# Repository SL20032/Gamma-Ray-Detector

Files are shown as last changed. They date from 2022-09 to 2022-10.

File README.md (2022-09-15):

# Gamma Ray Detector
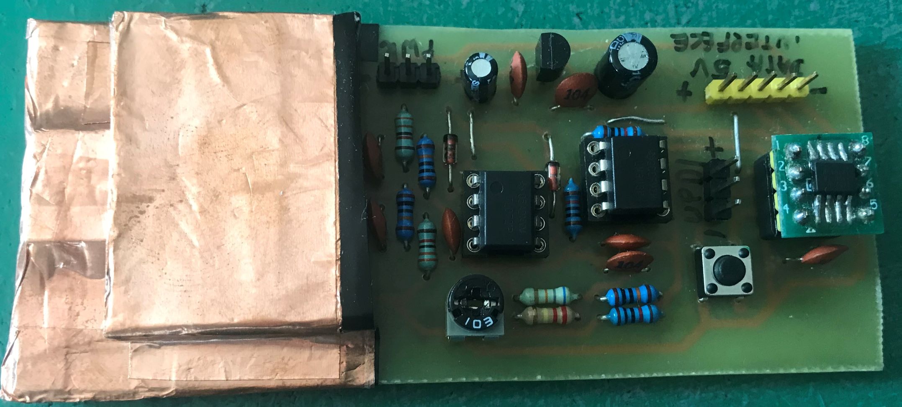
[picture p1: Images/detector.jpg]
Two head gamma particle detector

## Basic informations
Solid State gamma Ray detector based around PiN Diodeds (BPW34) as detection element and discreate transistor (BC549) as signal preamplifire (based on design published in Elektor magazine 06 - 2011). To increse detection rate of radiation while keeping good sensytivity espesialy for lower energy particles, device uses spit head approch - detection diodes are wired intu multiple detection heads (preamplifires) from witch output signal is then integrated and digitalized using compartor(LM393).

## Specs:
- Input voltage: 9V
- Data Procesing MCU: Attiny402 or pin compatible (so8 to dip8 adapter is nesesery in current board revision) 
## Theory of operation
TBA
## Digital signal procesing
Digital procesing is based on Attine402. Depending on the selected configuration data could be accese by a user e.g. through a COM port connection or an attached alfanumeric display. this solution supports counting all radioation events since device power up or counter reset (push button on the board) as well as a estimeted CPM (counts per minute). MCU firmware coming soon.
## Comparator circut calibration
To asure proper operation of detector's digital side nessesery is proper seting of reference voltage for comparator the easiest way to do this is:
- connect osciloscope to non inverting input of comparator (pin 3 on IC3) and to output of the same comparator (pin 1 on IC3)
- put the detector in area with minimal radiation (in most cases it is enought not to be in close procimty to ane designated sorce)
- dial the potenciometer (R19) until optput of a Comparator (IC3) stays low - set refernece voltage above a noice floor of a system
## Detection resoults 
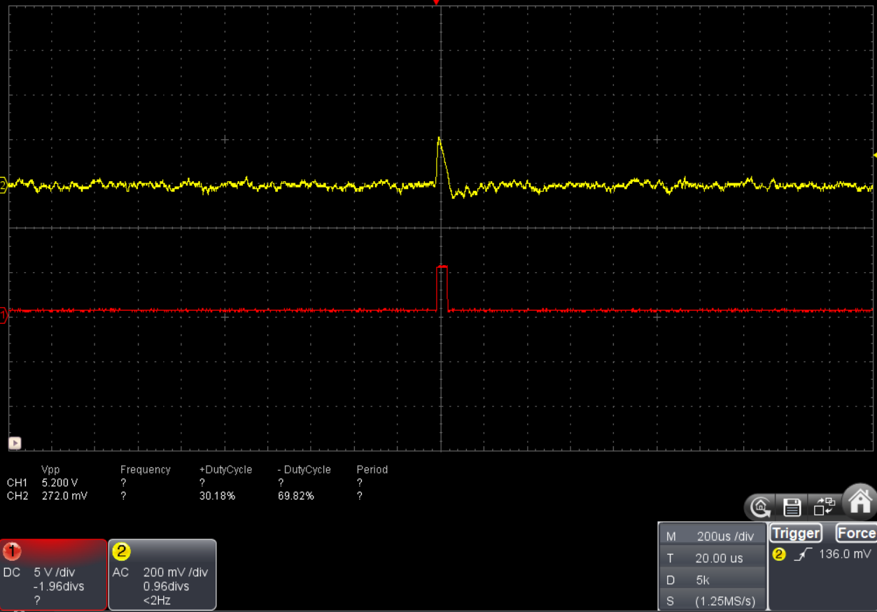
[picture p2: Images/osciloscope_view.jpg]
osciloscope view


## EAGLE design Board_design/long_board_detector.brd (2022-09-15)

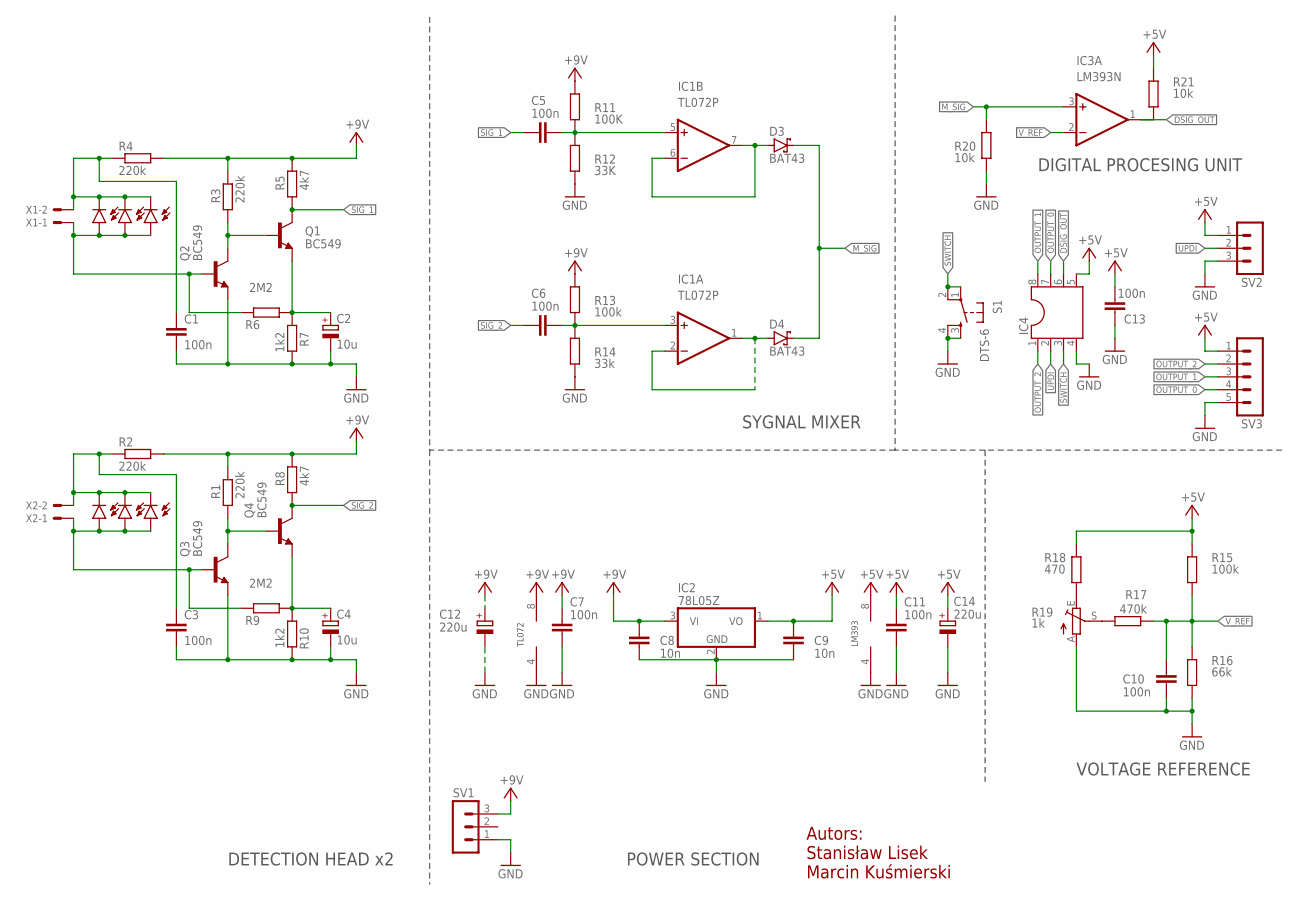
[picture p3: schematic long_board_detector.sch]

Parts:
C1, C3, C5, C6, C7, C10, C11, C13: 100n; C050-025X075
C2, C4: 10u; E2,5-6E
C8, C9: 10n; C050-025X075
C12, C14: 220u; E2,5-6E
D1, D2, D5, D6, D7, D8: BPW32
D3, D4: BAT43; DO35-10
IC1: TL072P; DIL08
IC2: 78L05Z; TO92
IC3: LM393N; DIL08
IC4: DIL8S; SOCKET-08
Q1, Q2, Q3, Q4: BC549; TO92-EBC
R1, R2, R3, R4: 220k; 0204/7
R5, R8: 4k7; 0204/7
R6, R9: 2M2; 0204/7
R7, R10: 1k2; 0204/7
R11: 100K; 0204/7
R12: 33K; 0204/7
R13, R15: 100k; 0204/7
R14: 33k; 0204/7
R16: 66k; 0204/7
R17: 470k; 0204/7
R18: 470; 0204/7
R19: 1k; CA6V
R20, R21: 10k; 0204/7
S1: DTS-6
SV1, SV2: MA03-1
SV3: MA05-1
X1, X2: 22-23-2021

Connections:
+3V3: C9.1, C11.2, C13.2, C14.+, IC2.1 (VO), IC3.8 (V+), IC4.5, R15.1, R18.2, R21.1, SV2.1, SV3.1
+5V: C7.2, C8.1, C12.+, IC1.8 (V+), IC2.3 (VI), R1.2, R2.2, R3.2, R4.2, R5.2, R8.2, R11.1, R13.1, SV1.3
DSIG_OUT: IC3.1 (OUT), IC4.6, R21.2
GND: C1.2, C2.-, C3.2, C4.-, C7.1, C8.2, C9.2, C10.2, C11.1, C12.-, C13.1, C14.-, IC1.4 (V-), IC2.2 (GND), IC3.4 (V-), IC4.4, Q2.E, Q3.E, R7.2, R10.2, R12.2, R14.2, R16.2, R19.A, R20.2, S1.3, S1.4, SV1.1, SV2.3, SV3.5
M_SIG: D3.C, D4.C, IC3.3 (+IN), R20.1
unnamed: D6.A, D7.A, D8.A, Q3.B, R9.2, X2.1
unnamed: C5.2, IC1.5 (+IN), R11.2, R12.1
unnamed: Q1.B, Q2.C, R3.1
unnamed: D1.A, D2.A, D5.A, Q2.B, R6.2, X1.1
unnamed: D4.A, IC1.1 (OUT), IC1.2 (-IN)
unnamed: D3.A, IC1.6 (-IN), IC1.7 (OUT)
unnamed: C2.+, Q1.E, R6.1, R7.1
unnamed: C6.2, IC1.3 (+IN), R13.2, R14.1
unnamed: C1.1, D1.K (C), D2.K (C), D5.K (C), R4.1, X1.2
unnamed: C3.1, D6.K (C), D7.K (C), D8.K (C), R2.1, X2.2
unnamed: Q3.C, Q4.B, R1.1
unnamed: C4.+, Q4.E, R9.1, R10.1
unnamed: R17.1, R19.S
unnamed: R18.1, R19.E
OUTPUT_0: IC4.7, SV3.4
OUTPUT_1: IC4.8, SV3.3
OUTPUT_2: IC4.1, SV3.2
SIG_1: C5.1, Q1.C, R5.1
SIG_2: C6.1, Q4.C, R8.1
SWITCH: IC4.3, S1.1, S1.2
UPDI: IC4.2, SV2.2
V_REF: C10.1, IC3.2 (-IN), R15.2, R16.1, R17.2

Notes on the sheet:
TL072
DETECTION HEAD x2
POWER SECTION
VOLTAGE REFERENCE
SYGNAL MIXER
DIGITAL PROCESING UNIT
LM393
Autors: Stanisław Lisek Marcin Kuśmierski

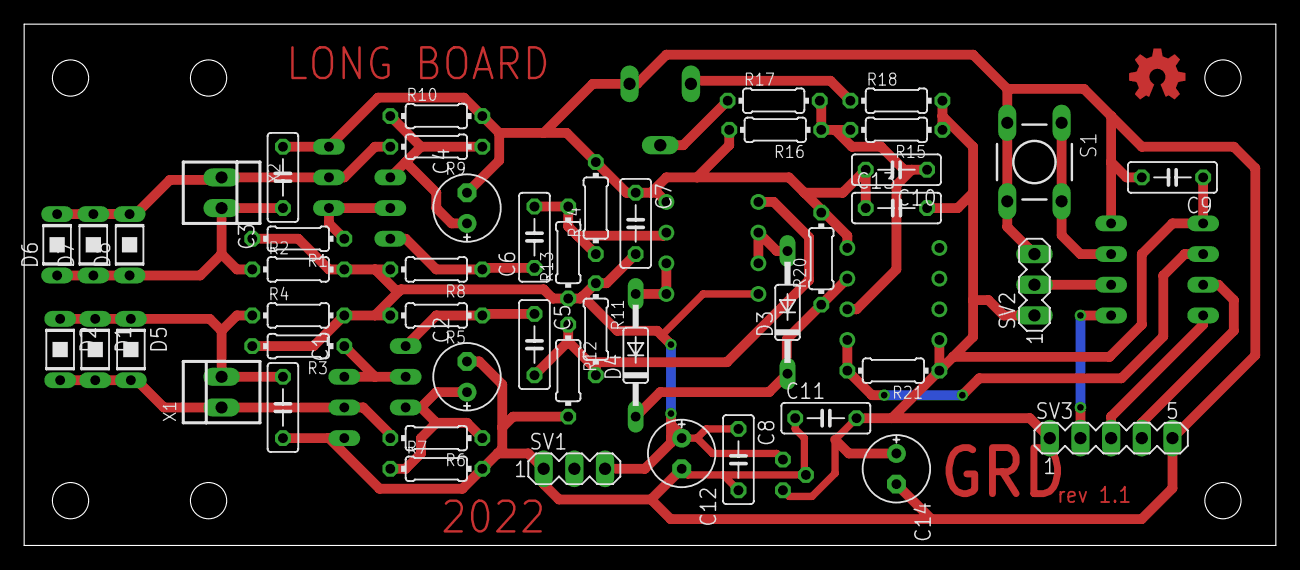
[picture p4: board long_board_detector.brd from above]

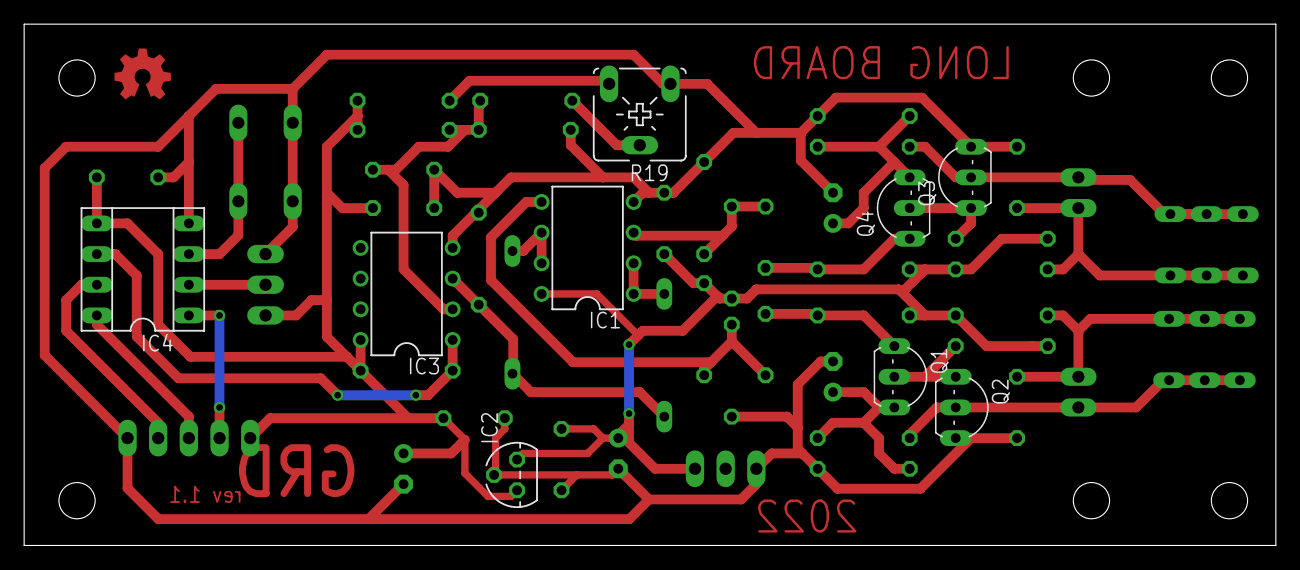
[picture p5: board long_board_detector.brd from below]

Board: 2 copper layers, 103.6 x 43.2 mm, 57 parts (9 on the bottom side), 27 nets.

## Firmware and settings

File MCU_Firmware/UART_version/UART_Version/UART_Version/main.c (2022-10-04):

/*
 * UART_Version.c
 *
 * Created: 30.09.2022 10:02:41
 * Author : SL20032
 */ 

#include <avr/io.h>
#include <avr/cpufunc.h>
#include <util/delay.h>

#include "UART.h"
#include "Counter.h"

void CLK_init(void)
{
	//internal oscillator set by fuse to 20 MHz
	ccp_write_io((void*) & (CLKCTRL.MCLKCTRLA), (CLKCTRL_CLKSEL_OSC20M_gc));	//set clock src to 20/16 MHz internal oscillator
	ccp_write_io((void *)&(CLKCTRL.MCLKCTRLB), CLKCTRL_PDIV_4X_gc | 1 << CLKCTRL_PEN_bp);	//prescaller 4
}


int main(void)
{
	CLK_init();
    UART_Init();
	COUNTER_Init();
	sei();
	
    while (1) 
    {
		UART_Send_Frame(Read_Counter(),Read_CPM());
		_delay_ms(100);
    }
}

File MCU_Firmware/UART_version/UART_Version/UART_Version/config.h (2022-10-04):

/*
 * config.h
 *
 * Created: 30.09.2022 10:12:07
 *  Author: SL20032
 */ 


#ifndef CONFIG_H_
#define CONFIG_H_

#define SENSOR_PORT		PORTA
#define SENSOR_PIN		PIN6_bm
#define SENSOR_PIN_CR	PIN6CTRL
#define SENSOR_IQR		PORT_INT6_bp

#define UART_TX_PORT	PORTA
#define UART_TX_PIN		PIN1_bm

#define UART_RX_PORT	PORTA
#define UART_RX_PIN		PIN2_bm

#define UART_BAUDRATE	9600

#define PUSHBUTTON_PORT	PORTA
#define PUSHBUTTON_PIN	PIN3_bm

#define CPM_ARR_SIZE	5
#define CPM_PERIOD_S	5

#endif /* CONFIG_H_ */

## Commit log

2022-09-15 Add PCB design
    [long_board_detector.brd, long_board_detector.sch]
2022-09-15 Readme and brd design update
    [long_board_detector.brd, long_board_detector.sch]
2022-09-30 UART MCU Firmware
